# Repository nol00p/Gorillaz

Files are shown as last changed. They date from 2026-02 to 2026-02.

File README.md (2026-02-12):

# Gorillaz PCB Boards

This project offers an integrated PCB replacement for the Kinesys Advantage2. The view of this project is to offer a full PCB replacement including the thumb clusters.
The PCB components are almost fully SMD. The Draw back will be the cost of the solution on order, but the benefit will be solderless solution. 

### How is it different from other mods

Aside from being a fun project the main goal of this is to offer a simplified approach to Kinesys moddiing. 
- solder free installation (as much as possible)
- battery management with the ability to wake the board up from sleep by pressing a key (not possible with the nice!nano)
- Bluetooth

If there are feature you would like to see supported on the board, do get in touch. 
note that I am not planning on supporting the pedals at this stage.

### The Hardware

### The Software
the firmware will be ZMK. 

## Attribution
This project would not be possible without the huge work done by 
https://github.com/dcpedit/pillzmod

The pcb design wouldn't have been possible withouth the guide from Moritz ebastler - https://github.com/ebastler/zmk-designguide

## Contribustions 
I am no pcb designer so I am very much looking for contributions and feedback to get the project to the finish line. 

## Current design
### Schema
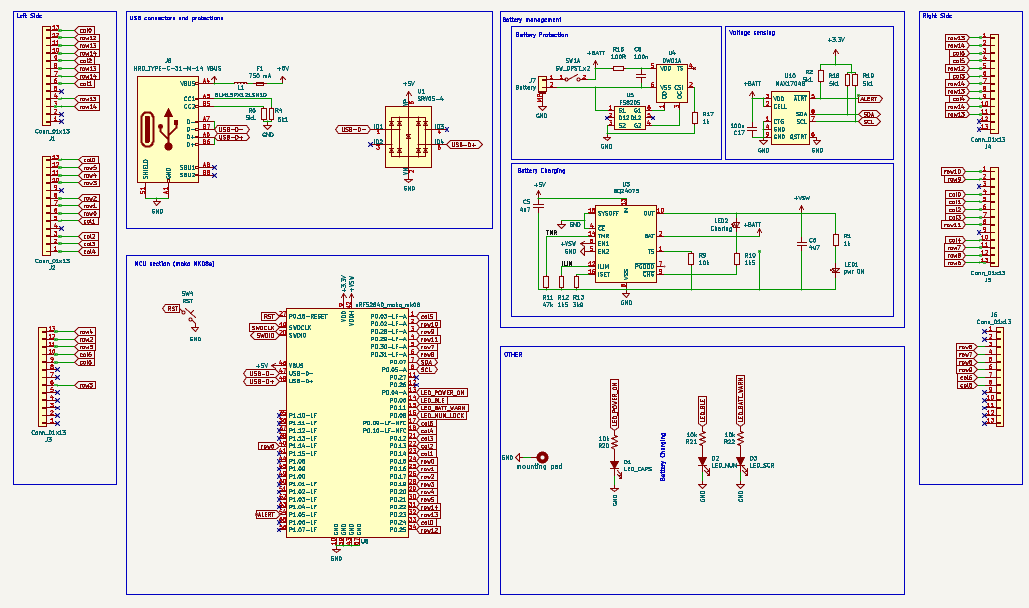
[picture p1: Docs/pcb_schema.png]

### pcb
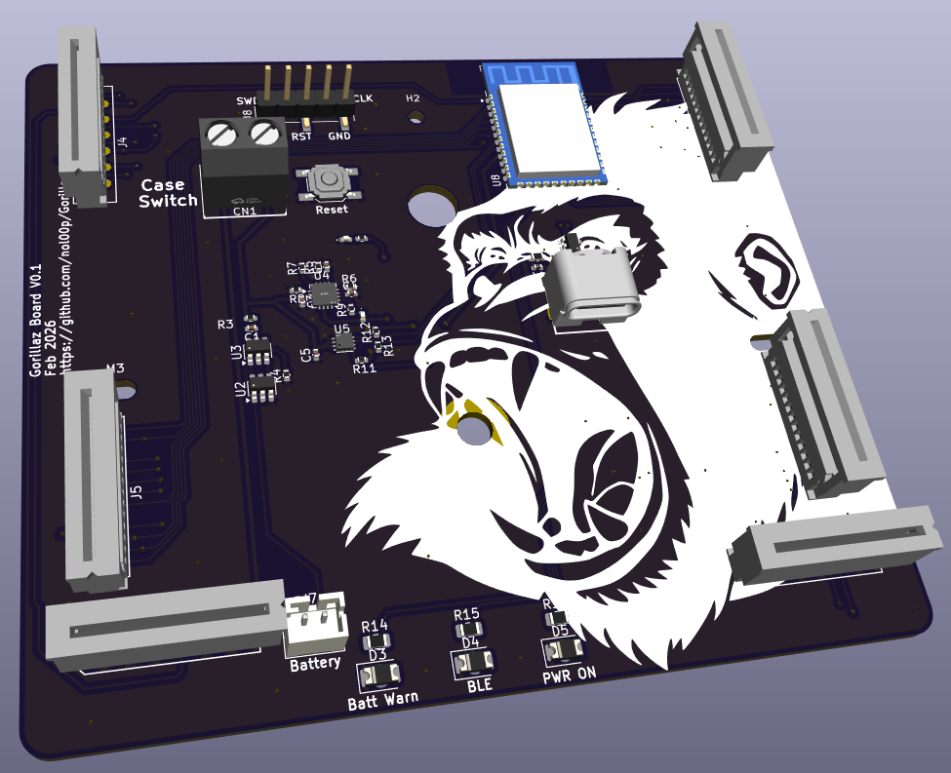
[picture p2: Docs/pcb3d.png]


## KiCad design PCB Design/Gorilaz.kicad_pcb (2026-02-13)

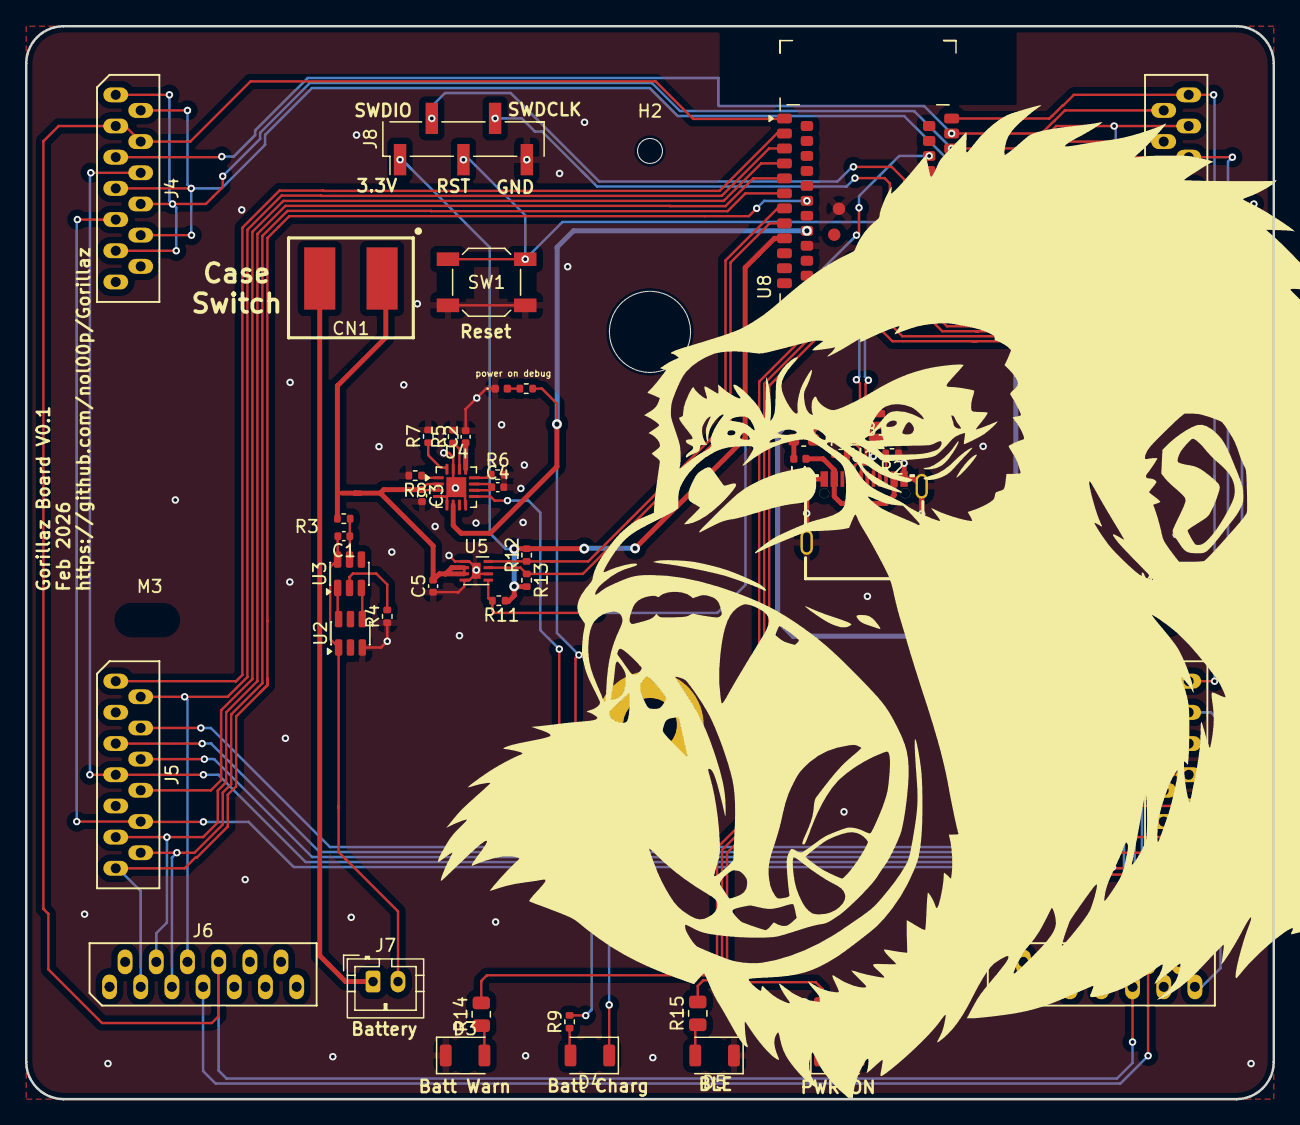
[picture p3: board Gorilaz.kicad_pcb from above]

Board: 2 copper layers, 100.0 x 86.0 mm, 50 parts (0 on the bottom side), 58 nets.

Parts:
C1, C5: 100n; C_0402_1005Metric
C2, C3, C4: 4u7; C_0402_1005Metric
CN1: 950-D-SMD-DS/02; CONN-SMD_2P-P5.00_950-D-SMD-DS-02
D1: LED_PWON; LED_1206_3216Metric_ReverseMount_Hole1.8x2.4mm
D2: pwr ON; LED_0402_1005Metric
D3: LED_BATT_WARN; LED_1206_3216Metric_ReverseMount_Hole1.8x2.4mm
D4: LED_CHARGING; LED_1206_3216Metric_ReverseMount_Hole1.8x2.4mm
D5: LED_BLE; LED_1206_3216Metric_ReverseMount_Hole1.8x2.4mm
F1: 750 mA; Fuse_0603_1608Metric
H1: mounting pad; MountingHole_4.3mm_M4_Pad
H2: mounting pad; MountingHole_2mm
J1, J2, J3, J4, J5, J6: Conn_01x13; Molex_0039532135
J7: Battery; JST_PH_B2B-PH-K_1x02_P2.00mm_Vertical
J8: Conn_01x05_MountingPin; PinHeader_1x05_P2.54mm_Vertical_SMD_Pin1Left
L1: BLM15PX121SN1D; L_0402_1005Metric
M1: MountingHole_6.4mm_M6
M3, M4: MountingHole_4.3mm_M4
R1, R2, R11, R12, R13: 5k1; R_0402_1005Metric
R3: 100R; R_0402_1005Metric
R4, R10: 1k; R_0402_1005Metric
R5: 47k; R_0402_1005Metric
R6, R9: 1k5; R_0402_1005Metric
R7: 3k9; R_0402_1005Metric
R8: 10k; R_0402_1005Metric
R14, R15, R16: 10k; R_0805_2012Metric
SW1: RST; SW_SPST_SKQG_WithStem
U1: SRV05-4; SOT-23-6
U2: FS8205; SOT-23-6
U3: DW01A; SOT-23-6
U4: BQ24075; VQFN-16-1EP_3x3mm_P0.5mm_EP1.6x1.6mm
U5: MAX17048; DFN-8-1EP_2x2mm_P0.5mm_EP0.7x1.3mm
U8: nRF52840_moko_mk08
USB1: USB-310M-B-SU; USB-C-SMD_USB-310M-B-SU

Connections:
+3.3V: J8.1, R11.2, R12.2, R13.2, U8.9 (VDD)
+5V: C2.1, F1.2, U1.5 (VP), U4.13 (IN), U8.46 (VBUS)
+BATT: C3.1, C5.2, CN1.2, R3.1, U4.2 (BAT), U4.3 (BAT), U5.2 (CELL), U5.3 (VDD)
+VSW: C4.1, D4.1 (K), R10.2, U4.6 (EN1), U4.10 (OUT), U4.11 (OUT), U8.42 (VDDH)
/ILIM: R6.1, U4.12 (ILIM)
/TMR: R5.1, U4.14 (TMR)
ALERT: R11.1, U5.5 (~ALRT), U8.54 (P1.05-LF)
GND: C2.2, C3.2, C4.2, C5.1, D1.2 (A), D2.1 (K), D3.1 (K), D5.1 (K), H1.1, J8.5, R1.1, R2.1, R4.1, R5.2, R6.2, R7.2, R8.2, SW1.2, U1.2 (VN), U2.3 (S2), U4.4 (~CE), U4.5 (EN2), U4.8 (VSS), U4.15 (SYSOFF), U4.17 (VSS), U5.1 (CTG), U5.4 (GND), U5.6 (QSTRT), U5.9 (GND), U8.10 (GND), U8.39 (GND), U8.43 (GND), U8.57 (GND), USB1.1 (SHELL), USB1.2 (SHELL), USB1.3 (SHELL), USB1.4 (SHELL), USB1.A1B12 (GND), USB1.B1A12 (GND)
LED_BATT_WARN: R14.2, U8.13 (P0.04-A)
LED_BLE: R15.2, U8.14 (P0.06)
LED_POWER_ON: R16.2, U8.15 (P0.11)
unnamed: D1.1 (K), R16.1
unnamed: D2.2 (A), R10.1
unnamed: D3.2 (A), R14.1
unnamed: D4.2 (A), R9.1
unnamed: D5.2 (A), R15.1
unnamed: F1.1, L1.2
unnamed: CN1.1, J7.1
unnamed: C1.2, J7.2, U2.1 (S1), U3.6 (VSS)
unnamed: U2.6 (G1), U3.1 (OD)
unnamed: U2.4 (G2), U3.3 (OC)
unnamed: R4.2, U3.2 (CSI)
unnamed: C1.1, R3.2, U3.5 (VDD)
unnamed: R7.1, U4.16 (ISET)
unnamed: R8.1, U4.1 (TS)
unnamed: R9.2, U4.9 (~CHG)
unnamed: R1.2, USB1.A5 (CC1)
unnamed: R2.2, USB1.B5 (CC2)
RST: J8.3, SW1.1, U8.27 (P0.18-RESET)
SCL: R13.1, U5.7 (SCL), U8.8 (P0.05-A)
SDA: R12.1, U5.8 (SDA), U8.7 (P0.07)
SWDCLK: J8.4, U8.19 (SWDCLK)
SWDIO: J8.2, U8.20 (SWDIO)
USB-D+: U8.48 (USB-D+), USB1.A6 (DP1), USB1.B6 (DP2)
USB-D-: U8.47 (USB-D-), USB1.A7 (DN1), USB1.B7 (DN2)
VBUS: L1.1, USB1.B4A9 (VBUS)
col0: J1.13, J2.13, J5.4, U8.34 (P0.25)
col1: J1.6, J2.5, J5.5, U8.29 (P0.20)
col2: J1.9, J2.3, J5.6, U8.30 (P0.21)
col3: J2.2, J4.6, J5.7, U8.21 (P0.12)
col4: J2.1, J4.9, J5.10, U8.18 (P0.10-LF-NFC)
col5: J3.9, J4.3, J4.4, J6.8, U8.1 (P0.03-LF-A)
col6: J3.10, J6.7, U8.17 (P0.09-LF-NFC)
row0: J2.6, U8.22 (P0.13)
row1: J2.7, U8.23 (P0.14)
row2: J2.8, J3.12, U8.24 (P0.15)
row3: J2.10, J3.6, U8.25 (P0.16)
row4: J2.11, J3.13, U8.26 (P0.17)
row5: J2.12, J3.11, U8.28 (P0.19)
row6: J5.13, J6.3, U8.40 (P1.14-LF)
row7: J5.11, J6.4, U8.5 (P0.30-LF-A)
row8: J5.12, J6.5, U8.6 (P0.31-LF-A)
row9: J5.2, J6.6, U8.3 (P0.28-LF-A)
row10: J5.1, U8.2 (P0.02-LF-A)
row11: J5.8, U8.4 (P0.29-LF-A)
row12: J1.12, J4.5, U8.33 (P0.24)
row13: J1.4, J1.8, J1.11, J4.1, J4.8, J4.11, U8.32 (P0.23)
row14: J1.3, J1.7, J1.10, J4.2, J4.7, J4.10, U8.31 (P0.22)

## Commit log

2026-01-27 LED package
    [Gorilaz.kicad_sch]
2026-01-29 schema update
    [Gorilaz.kicad_pcb, Gorilaz.kicad_sch]
2026-01-31 Data lane correction
    [Gorilaz.kicad_pcb, Gorilaz.kicad_sch]
2026-01-31 USB-C update
    [Gorilaz.kicad_pcb, Gorilaz.kicad_sch]
2026-02-02 power managemnt rework
    [Gorilaz.kicad_pcb, Gorilaz.kicad_sch]
2026-02-04 big updates push
    [Gorilaz.kicad_pcb, Gorilaz.kicad_sch]
2026-02-06 render update
    [Gorilaz.kicad_pcb, Gorilaz.kicad_sch]
2026-02-09 update pre-prod
    [Gorilaz.kicad_pcb, Gorilaz.kicad_sch]
2026-02-11 ESD update
    [Gorilaz.kicad_pcb, Gorilaz.kicad_sch]
2026-02-12 lots of improvement
    [Gorilaz.kicad_pcb, Gorilaz.kicad_sch]
2026-02-12 clean up
    [Gorilaz.kicad_pcb, Gorilaz.kicad_sch]
2026-02-13 LED update
    [Gorilaz.kicad_pcb, Gorilaz.kicad_sch]
